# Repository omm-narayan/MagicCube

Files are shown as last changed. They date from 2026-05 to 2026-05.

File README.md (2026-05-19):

# MagicCube
**Multi-Sensor Embedded Platform — v2.1**

Compact ESP32-S3 sensor node exposing a real-time web dashboard over a self-hosted Wi-Fi access point. Designed for rapid deployment in robotics prototyping, environment characterisation, and motion-capture applications.

---

## Platform

| Parameter | Value |
|---|---|
| MCU | ESP32-S3 Dev Module |
| I2C Bus | SDA GPIO 8 / SCL GPIO 9 / 400 kHz |
| Access Point | SSID `MagicCube`, open, IP `192.168.4.1` |
| Poll Rate | 50 ms |
| Power | 3.3 V rail throughout |

---

## Sensor Suite

| Sensor | Bus Address | Measurements |
|---|---|---|
| BME688 | `0x76` | Temperature, Humidity, Pressure, Gas Resistance, Altitude (derived), Dew Point (derived), Heat Index (derived) |
| BNO055 | `0x28` | Accelerometer XYZ (m/s2), Gyroscope XYZ (deg/s), Magnetometer XYZ (uT), Euler RPY (deg), Quaternion WXYZ |
| VL53L1X | `0x29` | Distance (mm), Velocity (m/s, EMA-filtered) |
| TSL2561 | `0x39` | Illuminance (lux) |

---

## Electrical Interface

All sensors share a single I2C bus. The table below details every pin connection required for correct operation. Do not leave address-select or mode-select pins floating.

### Common Bus

| Signal | ESP32-S3 GPIO |
|---|---|
| SDA | 8 |
| SCL | 9 |
| XSHUT (VL53L1X only) | 3 |

---

### BME688

Mode select: I2C is active when CS is held HIGH. SDO sets the 7-bit address LSB.

| BME688 Pin | Connection | Note |
|---|---|---|
| VCC | 3.3 V | |
| GND | GND | |
| SDI | GPIO 8 | I2C data |
| SCK | GPIO 9 | I2C clock |
| SDO | GND | Address LSB = 0, resolves to `0x76` |
| CS | 3.3 V | Must be HIGH to enable I2C mode |

> Pull SDO to 3.3 V to shift address to `0x77`. CS floating or LOW disables I2C.

---

### BNO055

PS0 and PS1 select the serial protocol. ADR sets the 7-bit address LSB.

| BNO055 Pin | Connection | Note |
|---|---|---|
| VCC | 3.3 V | |
| GND | GND | |
| SDA | GPIO 8 | I2C data |
| SCL | GPIO 9 | I2C clock |
| PS0 | GND | Protocol select — I2C mode |
| PS1 | GND | Protocol select — I2C mode |
| ADR | 3.3 V | Address LSB = 1, resolves to `0x28` |
| NRST | 3.3 V or float | Active-low reset, leave unconnected if unused |

> Pull ADR to GND to shift address to `0x29`. External crystal is enabled in firmware via `setExtCrystalUse(true)`.

---

### VL53L1X

XSHUT is active-low. The firmware asserts GPIO 3 HIGH before I2C initialisation to bring the device out of hardware standby.

| VL53L1X Pin | Connection | Note |
|---|---|---|
| VCC | 3.3 V | |
| GND | GND | |
| SDA | GPIO 8 | I2C data |
| SCL | GPIO 9 | I2C clock |
| XSHUT | GPIO 3 | Driven HIGH in firmware; pull LOW to reset |
| GPIO1 | Not connected | Interrupt output, unused |

> Configured for Long distance mode, 20 ms timing budget, continuous ranging. Maximum range: 4 m.

---

### TSL2561

ADDR pin selects between three fixed I2C addresses.

| TSL2561 Pin | Connection | Note |
|---|---|---|
| VCC | 3.3 V | |
| GND | GND | |
| SDA | GPIO 8 | I2C data |
| SCL | GPIO 9 | I2C clock |
| ADDR | Leave floating | Resolves to `0x39` |
| INT | Not connected | Interrupt output, unused |

> Connecting ADDR to GND shifts address to `0x29` (conflicts with VL53L1X). Connecting to 3.3 V shifts to `0x49`. Leave floating for `0x39`.

---

## Derived Quantities

### Altitude
Derived from barometric pressure using the International Standard Atmosphere:

```
altitude = 44330 * (1 - (P / 1013.25) ^ 0.1903)    [metres]
```

### Dew Point
Magnus approximation:

```
alpha = (17.27 * T) / (237.3 + T) + ln(RH / 100)
T_dew = (237.3 * alpha) / (17.27 - alpha)            [degC]
```

### Heat Index
NWS regression (Steadman), computed in degF internally, returned in degC.

### Velocity
Differentiated from successive VL53L1X range measurements. Three-stage conditioning pipeline:

| Stage | Parameter | Value |
|---|---|---|
| Minimum time delta | MIN_DT | 20 ms |
| Noise gate (single-step jump) | MAX_VEL_JUMP | 3.0 m/s |
| Hard clamp | MAX_VEL_MS | +/- 5.0 m/s |
| EMA smoothing factor | VEL_ALPHA | 0.25 |

```
v_raw  = delta_distance_mm / delta_time_s / 1000.0    [m/s]
v_filt = 0.25 * v_raw + 0.75 * v_prev                 [m/s, EMA]
```

---

## Firmware Dependencies

Install via Arduino IDE Library Manager:

| Library | Author |
|---|---|
| Adafruit BME680 Library | Adafruit |
| Adafruit BNO055 | Adafruit |
| Adafruit Unified Sensor | Adafruit |
| VL53L1X | Pololu |
| Adafruit TSL2561 Unified | Adafruit |

Additional: `Wire`, `WiFi`, `WebServer` — bundled with ESP32 Arduino core.

---

## Build Configuration

| Setting | Value |
|---|---|
| Board | ESP32S3 Dev Module |
| Upload Speed | 921600 |
| USB Mode | Hardware CDC and JTAG |
| Partition Scheme | Default 4 MB |
| PSRAM | Disabled |

---

## Deployment

1. Flash firmware to the ESP32-S3.
2. Connect to Wi-Fi access point `MagicCube` (no passphrase).
3. Navigate to `http://192.168.4.1` in any browser.
4. Sensor status indicators in the dashboard header confirm successful initialisation.

Serial monitor at 115200 baud reports per-sensor initialisation status on startup.

---

## Troubleshooting

| Symptom | Probable Cause | Corrective Action |
|---|---|---|
| BME688 not detected | CS not tied HIGH | Connect CS to 3.3 V |
| BME688 address mismatch | SDO state undefined | Confirm SDO to GND for `0x76` |
| BNO055 not detected | PS0/PS1 selecting SPI | Confirm both PS0 and PS1 to GND |
| VL53L1X not detected | XSHUT held LOW | Confirm GPIO 3 wired to XSHUT; verify GPIO is initialised before `Wire.begin()` |
| TSL2561 address conflict | ADDR tied to GND | Leave ADDR floating for `0x39` |
| I2C bus lockup | Missing pull-up resistors | Add 4.7 kohm pull-ups on SDA and SCL to 3.3 V if not on breakout board |
| Velocity unstable | Mechanical vibration or fast motion | Decrease VEL_ALPHA toward 0.1 for heavier smoothing |
| Dashboard unreachable | Client not associated to AP | Confirm Wi-Fi association before navigating to `192.168.4.1` |

---

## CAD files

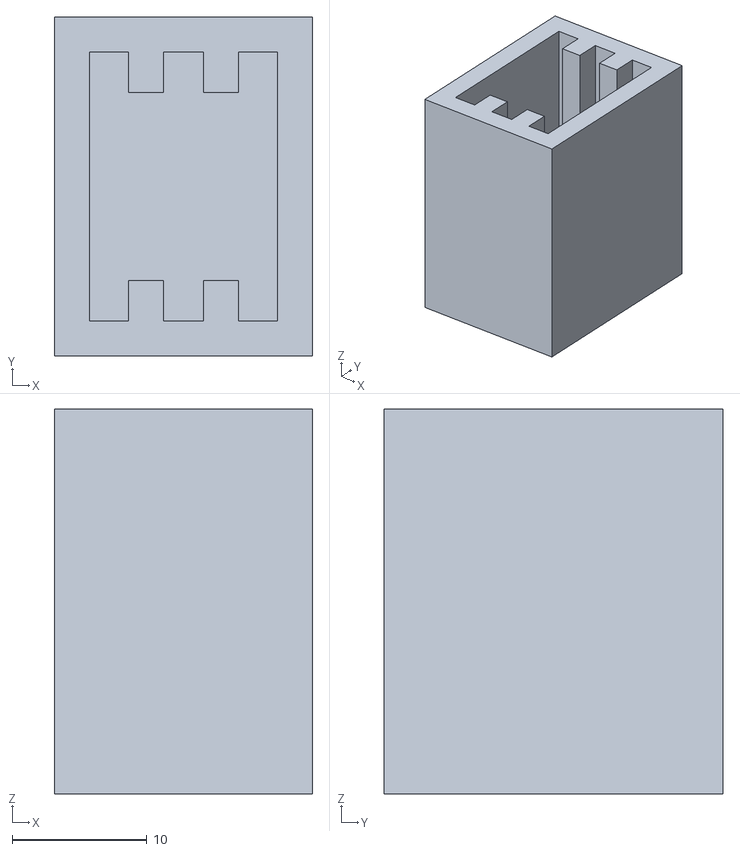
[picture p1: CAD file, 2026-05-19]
cad/inventor/Al2O3-250mg-capacitor.stl
19.2 x 25.2 x 28.6

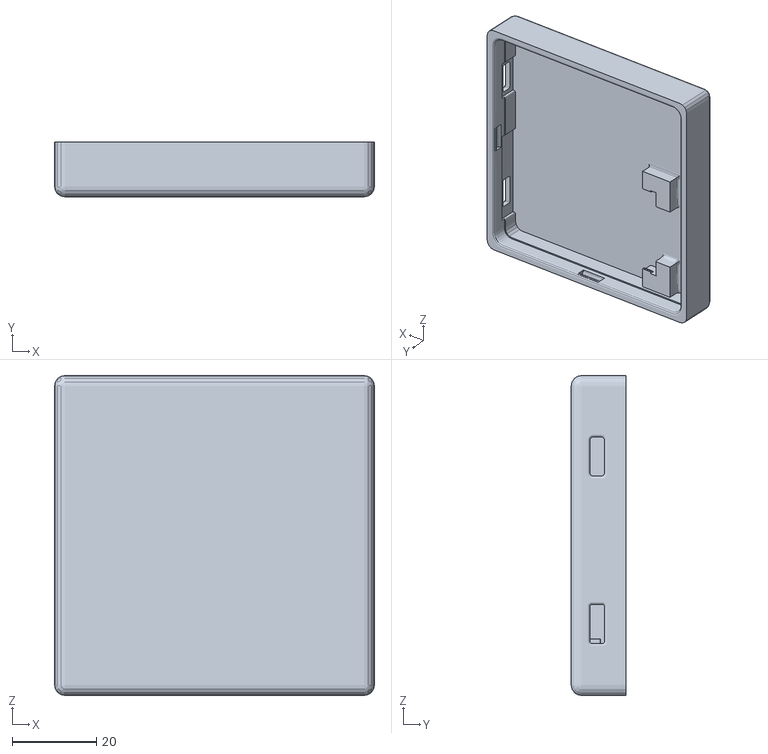
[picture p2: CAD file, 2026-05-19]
cad/inventor/STL/Bottom cover.stl
76.0 x 13.0 x 76.0

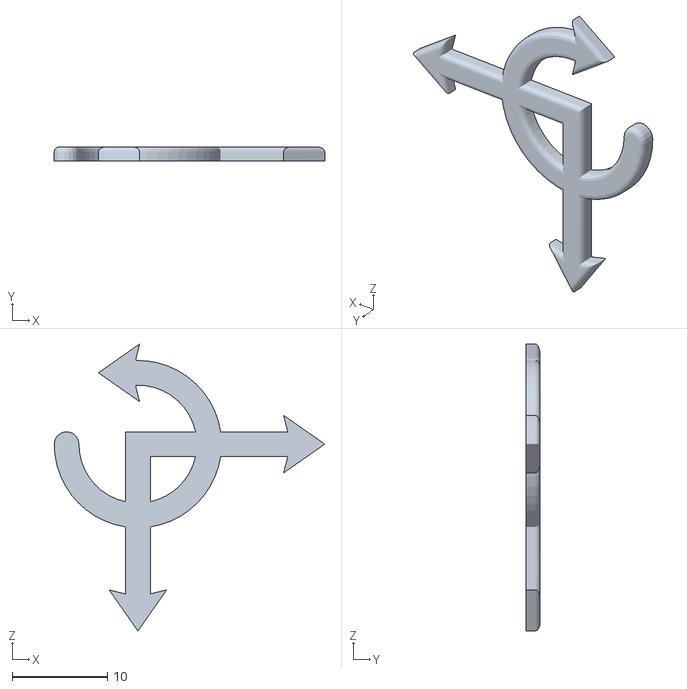
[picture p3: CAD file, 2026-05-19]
cad/inventor/STL/Logo.stl
28.5 x 1.50 x 30.2

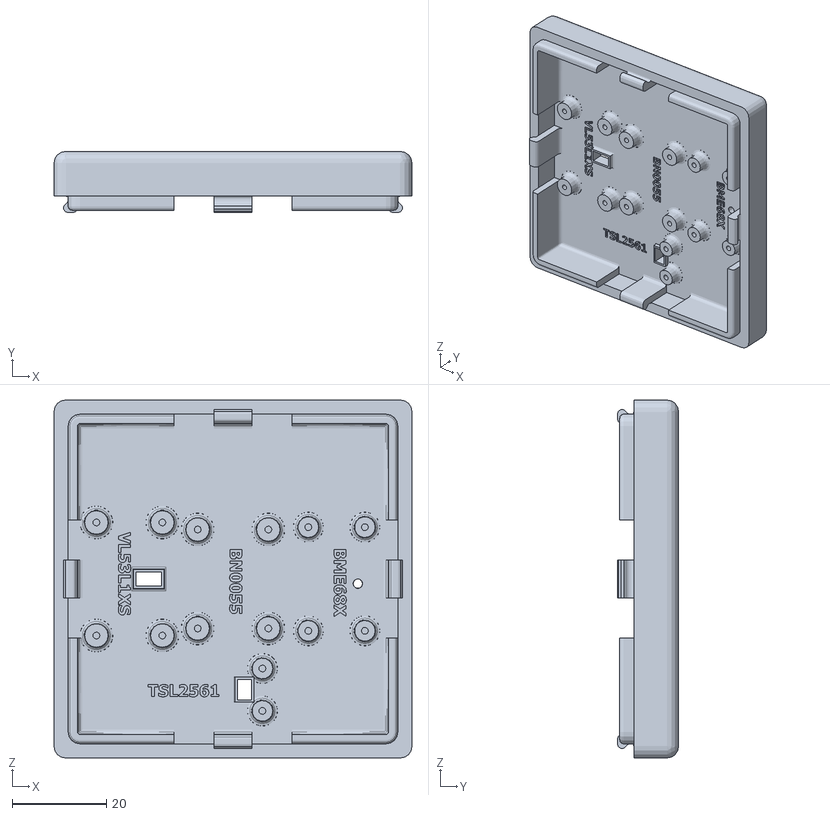
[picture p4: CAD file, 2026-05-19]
cad/inventor/STL/Top cover.stl
76.0 x 13.0 x 76.0

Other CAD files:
cad/fusion/MagicCube.f3d
cad/inventor/Bottom cover.ipt
cad/inventor/Logo.ipt
cad/inventor/MagicCube.iam
cad/inventor/OldVersions/Bottom Plate.0001.ipt
cad/inventor/OldVersions/Bottom cover.0009.ipt
cad/inventor/OldVersions/Logo.0017.ipt
cad/inventor/OldVersions/MagicCube.0003.iam
cad/inventor/OldVersions/Top cover.0015.ipt
cad/inventor/Top cover.ipt

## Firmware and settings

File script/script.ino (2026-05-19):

/*
 * ══════════════════════════════════════════════════════════════
 *  MagicCube — Advanced Multi-Sensor Dashboard  v2.1
 *  Connect to WiFi "MagicCube" (no password)
 *  Open browser → http://192.168.4.1
 * ══════════════════════════════════════════════════════════════
 *  BOARD : ESP32S3 Dev Module
 *  SDA   = GPIO 8   |   SCL = GPIO 9   |   XSHUT = GPIO 3
 *
 *  SENSORS (all share I²C bus):
 *  BME688  : SDO→GND, CS→3V3   → addr 0x76
 *            Temperature · Humidity · Pressure · Gas Resistance
 *            Altitude · Dew Point · Heat Index (derived)
 *  BNO055  : ADR→3V3            → addr 0x28
 *            Accel X/Y/Z · Gyro X/Y/Z · Mag X/Y/Z
 *            Euler Roll/Pitch/Yaw · Quaternion W/X/Y/Z
 *  VL53L1X : XSHUT→GPIO 3       → addr 0x29
 *            Distance (mm) · Velocity m/s (filtered)
 *  TSL2561 : ADDR→float          → addr 0x39
 *            Ambient Light (lux)
 *
 *  LIBRARIES (Sketch → Library Manager):
 *    Adafruit BME680 Library
 *    Adafruit BNO055
 *    Adafruit Unified Sensor
 *    VL53L1X by Pololu
 *    Adafruit TSL2561
 * ══════════════════════════════════════════════════════════════
 */

#include <Wire.h>
#include <WiFi.h>
#include <WebServer.h>
#include <Adafruit_Sensor.h>
#include <Adafruit_BME680.h>
#include <Adafruit_BNO055.h>
#include <VL53L1X.h>
#include <Adafruit_TSL2561_U.h>
#include <math.h>

#define SDA_PIN       8
#define SCL_PIN       9
#define XSHUT_PIN     3
#define SEA_LEVEL_HPA 1013.25f

// Velocity filtering parameters
#define VEL_ALPHA     0.25f     // Smoothing factor (0.1-0.5, lower = smoother)
#define MAX_VEL_MS    5.0f      // Max realistic velocity (m/s) ±5 m/s
#define MIN_DT        0.02f     // Minimum time delta (20ms) to avoid division by zero
#define MAX_VEL_JUMP  3.0f      // Max velocity jump per sample (m/s) for noise rejection

Adafruit_BME680          bme;
Adafruit_BNO055          bno(55, 0x28);
VL53L1X                  tof;
Adafruit_TSL2561_Unified tsl(TSL2561_ADDR_FLOAT, 12345);
WebServer                server(80);

bool bme_ok=false, bno_ok=false, tof_ok=false, tsl_ok=false;

struct SensorData {
  float temp=0, hum=0, pres=0, gas=0, alt=0, dew=0, heatIdx=0;
  float roll=0, pitch=0, yaw=0;
  float ax=0, ay=0, az=0;
  float gx=0, gy=0, gz=0;
  float mx=0, my=0, mz=0;
  float qw=1, qx=0, qy=0, qz=0;
  int   dist=0;
  float vel=0;        // Now in m/s (stabilized)
  float lux=0;
} D;

unsigned long lastTofMs=0;
int           lastTofDist=0;
float         velFiltered=0;
float         lastVelRaw=0;

float calcAltitude(float hPa){
  return 44330.0f*(1.0f-pow(hPa/SEA_LEVEL_HPA,0.1903f));
}

float calcDewPoint(float t,float rh){
  float a=17.27f,b=237.3f;
  float al=((a*t)/(b+t))+log(rh/100.0f);
  return (b*al)/(a-al);
}

float calcHeatIndex(float tc,float rh){
  float T=tc*9.0f/5.0f+32.0f;
  float HI=-42.379f+2.04901523f*T+10.14333127f*rh
           -0.22475541f*T*rh-6.83783e-3f*T*T
           -5.481717e-2f*rh*rh+1.22874e-3f*T*T*rh
           +8.5282e-4f*T*rh*rh-1.99e-6f*T*T*rh*rh;
  return (HI-32.0f)*5.0f/9.0f;
}

void readAll(){
  if(bme_ok && bme.performReading()){
    D.temp=bme.temperature; D.hum=bme.humidity;
    D.pres=bme.pressure/100.0f; D.gas=bme.gas_resistance/1000.0f;
    D.alt=calcAltitude(D.pres);
    D.dew=calcDewPoint(D.temp,D.hum);
    D.heatIdx=calcHeatIndex(D.temp,D.hum);
  }
  
  if(bno_ok){
    sensors_event_t e;
    bno.getEvent(&e,Adafruit_BNO055::VECTOR_EULER);
    D.yaw=e.orientation.x; D.pitch=e.orientation.y; D.roll=e.orientation.z;
    bno.getEvent(&e,Adafruit_BNO055::VECTOR_ACCELEROMETER);
    D.ax=e.acceleration.x; D.ay=e.acceleration.y; D.az=e.acceleration.z;
    bno.getEvent(&e,Adafruit_BNO055::VECTOR_GYROSCOPE);
    D.gx=e.gyro.x; D.gy=e.gyro.y; D.gz=e.gyro.z;
    bno.getEvent(&e,Adafruit_BNO055::VECTOR_MAGNETOMETER);
    D.mx=e.magnetic.x; D.my=e.magnetic.y; D.mz=e.magnetic.z;
    imu::Quaternion q=bno.getQuat();
    D.qw=q.w(); D.qx=q.x(); D.qy=q.y(); D.qz=q.z();
  }
  
  // STABILIZED VELOCITY CALCULATION (m/s)
  if(tof_ok){
    tof.read(false);
    int nd = tof.ranging_data.range_mm;
    unsigned long now = millis();
    
    if(lastTofMs > 0 && nd > 0) { 
      float dt = (now - lastTofMs) / 1000.0f;
      
      if(dt > MIN_DT) {
        // Raw velocity in mm/s, convert to m/s
        float rawVelMs = ((float)(nd - lastTofDist) / dt) / 1000.0f;
        
        // Noise rejection: ignore physically impossible jumps
        bool validReading = (fabs(rawVelMs - lastVelRaw) < MAX_VEL_JUMP) && 
                            (fabs(rawVelMs) < MAX_VEL_MS * 2);
        
        if(validReading) {
          // Exponential moving average filter for smooth velocity
          if(fabs(velFiltered) < 0.001f) {
            velFiltered = rawVelMs;  // First reading
          } else {
            velFiltered = VEL_ALPHA * rawVelMs + (1.0f - VEL_ALPHA) * velFiltered;
          }
          
          // Clamp to realistic range
          velFiltered = constrain(velFiltered, -MAX_VEL_MS, MAX_VEL_MS);
          lastVelRaw = rawVelMs;
        }
      }
    }
    
    lastTofDist = nd;
    lastTofMs = now;
    D.dist = nd;
    D.vel = velFiltered;  // Already in m/s
  }
  
  if(tsl_ok){ 
    sensors_event_t e; 
    tsl.getEvent(&e); 
    if(e.light>=0) D.lux=e.light; 
  }
}

void handleData(){
  readAll();
  char buf[1400];
  snprintf(buf,sizeof(buf),
    "{\"bme\":%s,\"bno\":%s,\"tof\":%s,\"tsl\":%s,"
    "\"temp\":%.1f,\"hum\":%.1f,\"pres\":%.1f,\"gas\":%.1f,\"alt\":%.1f,\"dew\":%.1f,\"heatIdx\":%.1f,"
    "\"roll\":%.1f,\"pitch\":%.1f,\"yaw\":%.1f,"
    "\"ax\":%.3f,\"ay\":%.3f,\"az\":%.3f,"
    "\"gx\":%.2f,\"gy\":%.2f,\"gz\":%.2f,"
    "\"mx\":%.2f,\"my\":%.2f,\"mz\":%.2f,"
    "\"qw\":%.4f,\"qx\":%.4f,\"qy\":%.4f,\"qz\":%.4f,"
    "\"dist\":%d,\"vel\":%.3f,\"lux\":%.1f}",
    bme_ok?"true":"false",bno_ok?"true":"false",
    tof_ok?"true":"false",tsl_ok?"true":"false",
    D.temp,D.hum,D.pres,D.gas,D.alt,D.dew,D.heatIdx,
    D.roll,D.pitch,D.yaw,
    D.ax,D.ay,D.az,D.gx,D.gy,D.gz,D.mx,D.my,D.mz,
    D.qw,D.qx,D.qy,D.qz,D.dist,D.vel,D.lux);
  server.sendHeader("Access-Control-Allow-Origin","*");
  server.send(200,"application/json",buf);
}

void handleRoot(){
  server.setContentLength(CONTENT_LENGTH_UNKNOWN);
  server.send(200,"text/html","");

  server.sendContent(F(R"HTML(<!DOCTYPE html>
<html lang="en">
<head>
<meta charset="UTF-8">
<meta name="viewport" content="width=device-width,initial-scale=1">
<title>MagicCube</title>
<link rel="preconnect" href="https://fonts.googleapis.com">
<link rel="stylesheet" href="https://fonts.googleapis.com/css2?family=DM+Sans:ital,opsz,wght@0,9..40,300;0,9..40,400;0,9..40,500;1,9..40,300&family=DM+Mono:wght@300;400&display=swap">
<script src="https://cdn.jsdelivr.net/npm/chart.js@4.4.0/dist/chart.umd.min.js"></script>
<style>
:root{
  --bg:#f5f5f7;
  --surface:#ffffff;
  --border:#e4e4e7;
  --border-inner:#f0f0f2;
  --text:#1d1d1f;
  --sub:#6e6e73;
  --muted:#aeaeb2;
  --accent:#0071e3;
  --green:#34c759;
  --red:#ff3b30;
  --orange:#ff9f0a;
  --purple:#5e5ce6;
  --teal:#32ade6;
  --pink:#ff375f;
  --r:14px;
}
*{box-sizing:border-box;margin:0;padding:0}
body{
  font-family:'DM Sans',sans-serif;
  background:var(--bg);color:var(--text);
  -webkit-font-smoothing:antialiased;
  min-height:100vh;
}

/* HEADER */
header{
  position:sticky;top:0;z-index:50;
  display:flex;align-items:center;justify-content:space-between;
  padding:13px 24px;
  background:rgba(245,245,247,.9);
  backdrop-filter:saturate(180%) blur(18px);
  -webkit-backdrop-filter:saturate(180%) blur(18px);
  border-bottom:1px solid var(--border);
}
.brand{display:flex;align-items:baseline;gap:8px}
.brand-name{font-size:1.1rem;font-weight:500;letter-spacing:-.015em}
.brand-ver{font-size:.68rem;color:var(--muted);font-weight:300;letter-spacing:.02em}
#ts{font-size:.7rem;color:var(--sub);font-family:'DM Mono',monospace;font-weight:300}

/* CHIP BAR */
.chipbar{
  display:flex;gap:7px;padding:9px 24px;
  background:var(--surface);
  border-bottom:1px solid var(--border);
  flex-wrap:wrap;
}
.chip{
  display:inline-flex;align-items:center;gap:5px;
  padding:3px 10px 3px 8px;border-radius:20px;
  font-size:.65rem;font-weight:400;letter-spacing:.04em;
  border:1px solid var(--border);color:var(--muted);background:transparent;
  transition:all .2s;
}
.chip.on{background:#e8f4fd;border-color:#b8d9f8;color:var(--accent)}
.cdot{width:5px;height:5px;border-radius:50%;background:var(--muted);flex-shrink:0;transition:background .2s}
.chip.on .cdot{background:var(--green)}

/* LAYOUT */
.page{padding:20px 24px 32px;display:flex;flex-direction:column;gap:26px}
.sec-label{
  font-size:.62rem;font-weight:500;text-transform:uppercase;
  letter-spacing:.1em;color:var(--muted);
  padding-bottom:9px;border-bottom:1px solid var(--border-inner);
  margin-bottom:2px;
}
.grid{display:grid;grid-template-columns:repeat(auto-fill,minmax(288px,1fr));gap:11px}

/* CARD */
.card{
  background:var(--surface);
  border:1px solid var(--border);
  border-radius:var(--r);
  padding:17px 17px 13px;
}
.card-lbl{
  font-size:.6rem;font-weight:500;text-transform:uppercase;
  letter-spacing:.1em;color:var(--muted);
  display:flex;align-items:center;justify-content:space-between;
  margin-bottom:11px;
}
.tag{
  font-size:.59rem;font-weight:400;letter-spacing:.02em;
  background:var(--bg);border:1px solid var(--border);
  color:var(--sub);padding:1px 7px;border-radius:8px;
  text-transform:none;
}

/* BIG NUMBER */
.big{
  font-size:2.25rem;font-weight:300;letter-spacing:-.025em;
  line-height:1.05;color:var(--text);margin-bottom:2px;
}
.big .u{font-size:.95rem;font-weight:300;color:var(--muted);margin-left:3px}
.hint{font-size:.7rem;color:var(--muted);margin-bottom:11px;font-weight:300;font-style:italic}

/* METRIC CELLS */
.row{display:grid;gap:7px;margin-bottom:9px}
.c2{grid-template-columns:1fr 1fr}
.c3{grid-template-columns:1fr 1fr 1fr}
.c4{grid-template-columns:1fr 1fr 1fr 1fr}
.cell{
  background:var(--bg);border-radius:9px;
  padding:8px 6px 7px;text-align:center;
  border:1px solid var(--border-inner);
}
.cl{font-size:.57rem;text-transform:uppercase;letter-spacing:.07em;color:var(--muted);margin-bottom:3px}
.cv{font-size:.88rem;font-weight:400;font-family:'DM Mono',monospace;color:var(--text)}
.cv.ac{color:var(--accent)} .cv.gr{color:var(--green)}
.cv.or{color:var(--orange)} .cv.pu{color:var(--purple)}
.cv.te{color:var(--teal)}   .cv.pk{color:var(--pink)}

/* CHART */
.ch{position:relative;width:100%}
.ch.h70{height:70px} .ch.h86{height:86px} .ch.h96{height:96px}

/* 3D CUBE */
.scene{display:flex;justify-content:center;align-items:center;height:96px;perspective:260px;margin-bottom:8px}
.cube{width:50px;height:50px;transform-style:preserve-3d;transition:transform .08s linear}
.face{
  position:absolute;width:50px;height:50px;
  background:rgba(0,113,227,.03);
  border:1px solid rgba(0,113,227,.15);
  display:flex;align-items:center;justify-content:center;
  font-size:.42rem;color:rgba(0,113,227,.35);letter-spacing:.08em;
  font-family:'DM Mono',monospace;
}
.f-fr{transform:translateZ(25px)} .f-bk{transform:rotateY(180deg) translateZ(25px)}
.f-lt{transform:rotateY(-90deg) translateZ(25px)} .f-rt{transform:rotateY(90deg) translateZ(25px)}
.f-tp{transform:rotateX(90deg) translateZ(25px)} .f-bt{transform:rotateX(-90deg) translateZ(25px)}

/* OFFLINE */
.off{padding:20px 0;text-align:center;color:var(--muted);font-size:.75rem;font-weight:300}

footer{
  padding:18px 24px;text-align:center;
  font-size:.63rem;color:var(--muted);letter-spacing:.04em;
  border-top:1px solid var(--border-inner);
}

@media(max-width:540px){
  .page{padding:13px 13px 24px}
  header,.chipbar{padding-left:13px;padding-right:13px}
  .big{font-size:1.8rem}
  .c4{grid-template-columns:1fr 1fr}
}
</style>
</head>
<body>

<header>
  <div class="brand">
    <span class="brand-name">MagicCube</span>
    <span class="brand-ver">Sensor Dashboard</span>
  </div>
  <div id="ts">Connecting…</div>
</header>

<div class="chipbar">
  <div class="chip" id="chip-bme"><span class="cdot"></span>BME688</div>
  <div class="chip" id="chip-bno"><span class="cdot"></span>BNO055</div>
  <div class="chip" id="chip-tof"><span class="cdot"></span>VL53L1X</div>
  <div class="chip" id="chip-tsl"><span class="cdot"></span>TSL2561</div>
</div>

<div class="page">

  <section>
    <div class="sec-label">Environment · BME688</div>
    <div class="grid">
      <div class="card" id="cd-temp"><div class="card-lbl">Temperature<span class="tag">°C</span></div><div class="off">Not connected</div></div>
      <div class="card" id="cd-hum"><div class="card-lbl">Humidity &amp; Comfort<span class="tag">% RH</span></div><div class="off">Not connected</div></div>
      <div class="card" id="cd-pres"><div class="card-lbl">Pressure &amp; Altitude<span class="tag">hPa · m</span></div><div class="off">Not connected</div></div>
      <div class="card" id="cd-gas"><div class="card-lbl">Gas Resistance<span class="tag">kΩ</span></div><div class="off">Not connected</div></div>
    </div>
  </section>

  <section>
    <div class="sec-label">Motion &amp; Orientation · BNO055</div>
    <div class="grid">
      <div class="card" id="cd-euler"><div class="card-lbl">Euler Orientation<span class="tag">°</span></div><div class="off">Not connected</div></div>
      <div class="card" id="cd-accel"><div class="card-lbl">Accelerometer<span class="tag">m/s²</span></div><div class="off">Not connected</div></div>
      <div class="card" id="cd-gyro"><div class="card-lbl">Gyroscope<span class="tag">°/s</span></div><div class="off">Not connected</div></div>
      <div class="card" id="cd-mag"><div class="card-lbl">Magnetometer<span class="tag">µT</span></div><div class="off">Not connected</div></div>
      <div class="card" id="cd-quat"><div class="card-lbl">Quaternion &amp; 3D Attitude</div><div class="off">Not connected</div></div>
    </div>
  </section>

  <section>
    <div class="sec-label">Distance &amp; Velocity · VL53L1X</div>
    <div class="grid">
      <div class="card" id="cd-dist"><div class="card-lbl">Distance<span class="tag">mm</span></div><div class="off">Not connected</div></div>
      <div class="card" id="cd-vel"><div class="card-lbl">Velocity (filtered)<span class="tag">m/s</span></div><div class="off">Not connected</div></div>
    </div>
  </section>

  <section>
    <div class="sec-label">Ambient Light · TSL2561</div>
    <div class="grid">
      <div class="card" id="cd-lux"><div class="card-lbl">Light Intensity<span class="tag">lux</span></div><div class="off">Not connected</div></div>
    </div>
  </section>

</div>

<footer>MagicCube v2.1 &nbsp;·&nbsp; ESP32-S3 &nbsp;·&nbsp; BME688 · BNO055 · VL53L1X · TSL2561 &nbsp;·&nbsp; Velocity filtered & stabilized in m/s</footer>
)HTML"));

  server.sendContent(F(R"JS(
<script>
const MAX=55,charts={},init={};

const C={
  blue:'#0071e3',green:'#34c759',orange:'#ff9f0a',
  purple:'#5e5ce6',teal:'#32ade6',pink:'#ff375f',
  amber:'#ffcc00',slate:'#8e8e93'
};

function mkChart(id,sets,o){
  const el=document.getElementById(id); if(!el)return null; o=o||{};
  return new Chart(el,{type:'line',
    data:{
      labels:Array(MAX).fill(''),
      datasets:sets.map(s=>({
        label:s.l,data:Array(MAX).fill(null),
        borderColor:s.c,backgroundColor:s.c+'12',
        borderWidth:1.5,pointRadius:0,
        fill:sets.length===1,tension:0.38
      }))
    },
    options:{
      animation:false,responsive:true,maintainAspectRatio:false,
      plugins:{legend:{
        display:sets.length>1,
        labels:{font:{family:'DM Mono',size:9},color:'#aeaeb2',boxWidth:8,padding:7}
      }},
      scales:{
        x:{display:false},
        y:{display:true,
          grid:{color:'#f0f0f2'},border:{color:'#f0f0f2'},
          ticks:{font:{family:'DM Mono',size:9},color:'#aeaeb2',maxTicksLimit:4},
          ...(o.min!==undefined?{min:o.min}:{}),
          ...(o.max!==undefined?{max:o.max}:{})
        }
      }
    }
  });
}

function push(c,...v){
  if(!c)return;
  v.forEach((val,i)=>{
    c.data.datasets[i].data.push(val);
    if(c.data.datasets[i].data.length>MAX) c.data.datasets[i].data.shift();
  });
  c.data.labels.push('');
  if(c.data.labels.length>MAX) c.data.labels.shift();
  c.update('none');
}

function $v(id,v){const e=document.getElementById(id);if(e)e.textContent=v;}

/* ── card builders ── */
function bTemp(){
  document.getElementById('cd-temp').innerHTML=`
    <div class="card-lbl">Temperature<span class="tag">°C</span></div>
    <div class="big"><span id="vt">--</span><span class="u">°C</span></div>
    <div class="hint">Ambient air temperature</div>
    <div class="ch h70"><canvas id="ch-t"></canvas></div>`;
  charts.temp=mkChart('ch-t',[{l:'°C',c:C.orange}]);
}
function bHum(){
  document.getElementById('cd-hum').innerHTML=`
    <div class="card-lbl">Humidity &amp; Comfort<span class="tag">% RH</span></div>
    <div class="big"><span id="vh">--</span><span class="u">%</span></div>
    <div class="row c3">
      <div class="cell"><div class="cl">Dew Point</div><div class="cv ac" id="vdew">--</div></div>
      <div class="cell"><div class="cl">Heat Index</div><div class="cv or" id="vhi">--</div></div>
      <div class="cell"><div class="cl">Feel</div><div class="cv gr" id="vfeel">--</div></div>
    </div>
    <div class="ch h70"><canvas id="ch-h"></canvas></div>`;
  charts.hum=mkChart('ch-h',[{l:'RH %',c:C.teal},{l:'Dew°C',c:C.blue}]);
}
function bPres(){
  document.getElementById('cd-pres').innerHTML=`
    <div class="card-lbl">Pressure &amp; Altitude<span class="tag">hPa · m</span></div>
    <div class="big"><span id="vp">--</span><span class="u">hPa</span></div>
    <div class="row c2">
      <div class="cell"><div class="cl">Altitude</div><div class="cv pu" id="valt">-- m</div></div>
      <div class="cell"><div class="cl">Sea Level</div><div class="cv te">1013 hPa</div></div>
    </div>
    <div class="ch h70"><canvas id="ch-p"></canvas></div>`;
  charts.pres=mkChart('ch-p',[{l:'hPa',c:C.purple},{l:'Alt m',c:C.green}]);
}
function bGas(){
  document.getElementById('cd-gas').innerHTML=`
    <div class="card-lbl">Gas Resistance<span class="tag">kΩ</span></div>
    <div class="big"><span id="vg">--</span><span class="u">kΩ</span></div>
    <div class="hint">Higher = cleaner air</div>
    <div class="ch h86"><canvas id="ch-g"></canvas></div>`;
  charts.gas=mkChart('ch-g',[{l:'kΩ',c:C.green}]);
}
function bEuler(){
  document.getElementById('cd-euler').innerHTML=`
    <div class="card-lbl">Euler Orientation<span class="tag">°</span></div>
    <div class="row c3">
      <div class="cell"><div class="cl">Roll</div><div class="cv gr" id="vroll">--</div></div>
      <div class="cell"><div class="cl">Pitch</div><div class="cv ac" id="vpitch">--</div></div>
      <div class="cell"><div class="cl">Yaw</div><div class="cv or" id="vyaw">--</div></div>
    </div>
    <div class="ch h96"><canvas id="ch-e"></canvas></div>`;
  charts.euler=mkChart('ch-e',[{l:'Roll',c:C.green},{l:'Pitch',c:C.blue},{l:'Yaw',c:C.orange}],{min:-180,max:180});
}
function bAccel(){
  document.getElementById('cd-accel').innerHTML=`
    <div class="card-lbl">Accelerometer<span class="tag">m/s²</span></div>
    <div class="row c3">
      <div class="cell"><div class="cl">X</div><div class="cv gr" id="vax">--</div></div>
      <div class="cell"><div class="cl">Y</div><div class="cv ac" id="vay">--</div></div>
      <div class="cell"><div class="cl">Z</div><div class="cv pk" id="vaz">--</div></div>
    </div>
    <div class="ch h96"><canvas id="ch-a"></canvas></div>`;
  charts.accel=mkChart('ch-a',[{l:'X',c:C.green},{l:'Y',c:C.blue},{l:'Z',c:C.pink}]);
}
function bGyro(){
  document.getElementById('cd-gyro').innerHTML=`
    <div class="card-lbl">Gyroscope<span class="tag">°/s</span></div>
    <div class="row c3">
      <div class="cell"><div class="cl">X</div><div class="cv gr" id="vgx">--</div></div>
      <div class="cell"><div class="cl">Y</div><div class="cv ac" id="vgy">--</div></div>
      <div class="cell"><div class="cl">Z</div><div class="cv pk" id="vgz">--</div></div>
    </div>
    <div class="ch h96"><canvas id="ch-gy"></canvas></div>`;
  charts.gyro=mkChart('ch-gy',[{l:'X',c:C.green},{l:'Y',c:C.blue},{l:'Z',c:C.pink}]);
}
function bMag(){
  document.getElementById('cd-mag').innerHTML=`
    <div class="card-lbl">Magnetometer<span class="tag">µT</span></div>
    <div class="row c3">
      <div class="cell"><div class="cl">X</div><div class="cv gr" id="vmx">--</div></div>
      <div class="cell"><div class="cl">Y</div><div class="cv ac" id="vmy">--</div></div>
      <div class="cell"><div class="cl">Z</div><div class="cv pu" id="vmz">--</div></div>
    </div>
    <div class="ch h96"><canvas id="ch-m"></canvas></div>`;
  charts.mag=mkChart('ch-m',[{l:'X µT',c:C.green},{l:'Y µT',c:C.blue},{l:'Z µT',c:C.purple}]);
}
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
void loop(){ 
  server.handleClient(); 
}
